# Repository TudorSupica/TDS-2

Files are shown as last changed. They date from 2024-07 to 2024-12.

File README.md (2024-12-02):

# The [TDS-2](https://github.com/TudorSupica/TDS-2/)

The TDS-2 is the next guitar pedal in the TDS series, with an improved design and use of a standard enclosure.

The main features of the TDS-2 are the use of clipping diodes and a buffering stage, before the op-amp that amplifies the base signal. I've also used a 3PDT footswitch and some audio jacks that hold the line low when no jack is inserted, just to make sure i don't get any unecessary noise.

3D_isometric

# Summary

The main features of the circuit are: 

- Buffer stage
- High amplification factor
- Clipping diodes
- Decoupling and bypass capacitors
- Standardised jack sockets, they pull the line low when not in use
- Barrel jack for power 
- 3PDT footswitch 
- Hammond 1590B Al enclosure

# [The Schematic](https://github.com/TudorSupica/TDS-2/blob/main/schematic/)

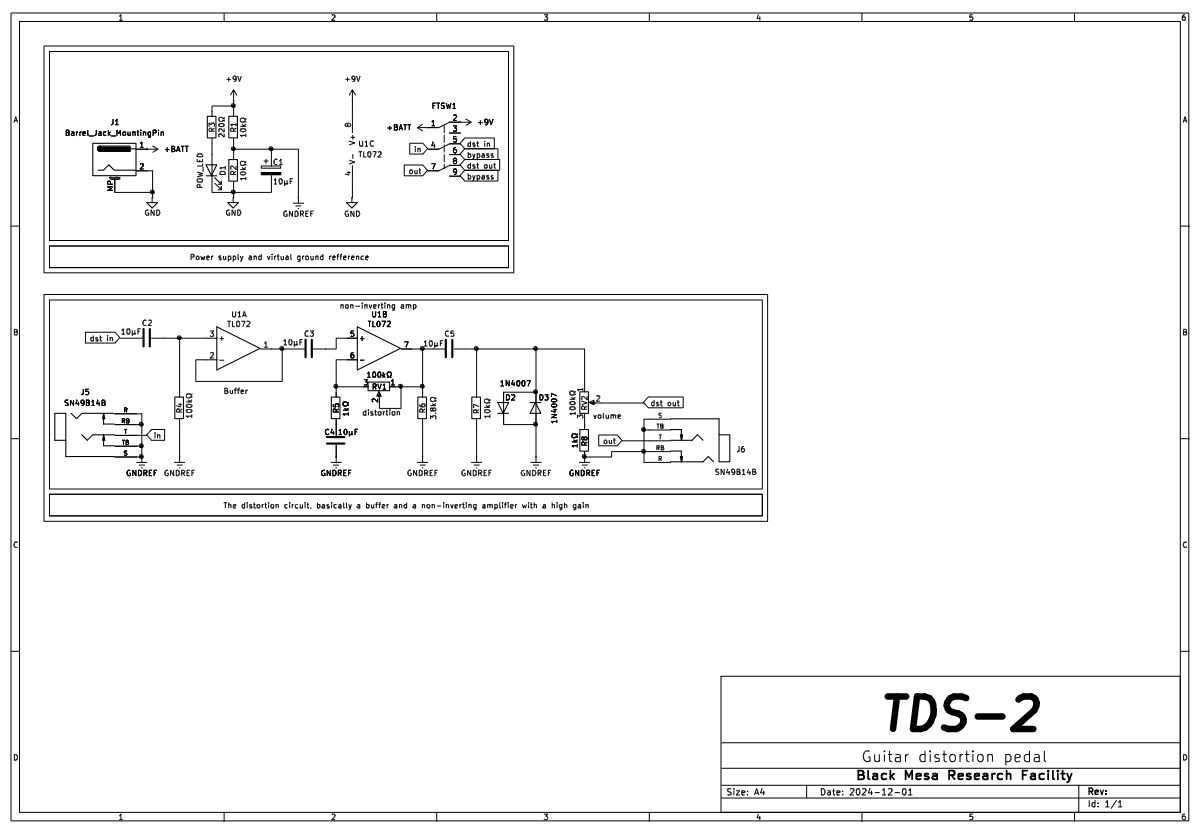
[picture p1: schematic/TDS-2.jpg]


The principle behind the TDS-2 distortion pedal is a high amplification factor. The TL072 IC has two op-amps. The first one is used as a buffer so that the imput signal is high enough. The second op-amp actually amplifies the signal, since it's in a inverting configuration to counter the phase shift of the buffer stage. 
The amplification factor is given by the potentiometer that connects the oputput back to the inverting input. The capacitors are used to decouple and "delete" any DC voltage that might be present. I used two fast switching diodes to make a clipping stage, to ensure that the signal never goes above and below the +4,5v and -4,5v headroom.

# [The PCB](https://github.com/TudorSupica/TDS-2/blob/main/PCB/)

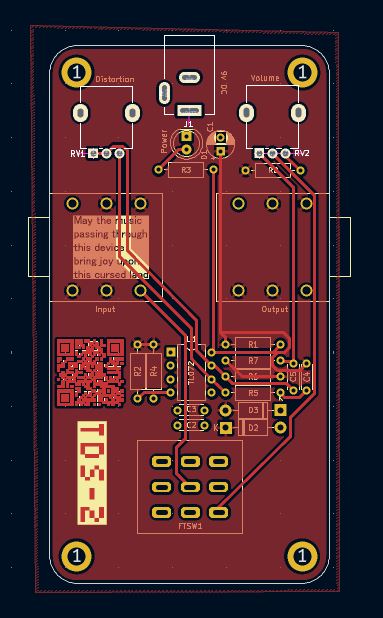
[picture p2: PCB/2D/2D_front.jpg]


The PCB also has four M3 mounting holes that are connected directly to 0v, so that when I mount it in the enclosure, the aluminium enclosure gets grounded and acts like an EMF shield.
One thing I'd improve upon are the traces since they're quite narrow and may be prone to high levels of noise.

# The Hammond 1590B enclosure

The enclosure I picked for this pedal and subsequent versions of it is the Hammond 1590B, since it's made out of aluminium it's relatively cheap and effective. The enclosure offers more of a professional look to the pedal whilst also doubling as protection against EMF and other elements.



I used this datasheet to get the dimensions needed for the PCB, and i found that 10cm x 5cm is more than enough. 

This project is not intended for beginners, but with a little guidance it can be a successful starting project.

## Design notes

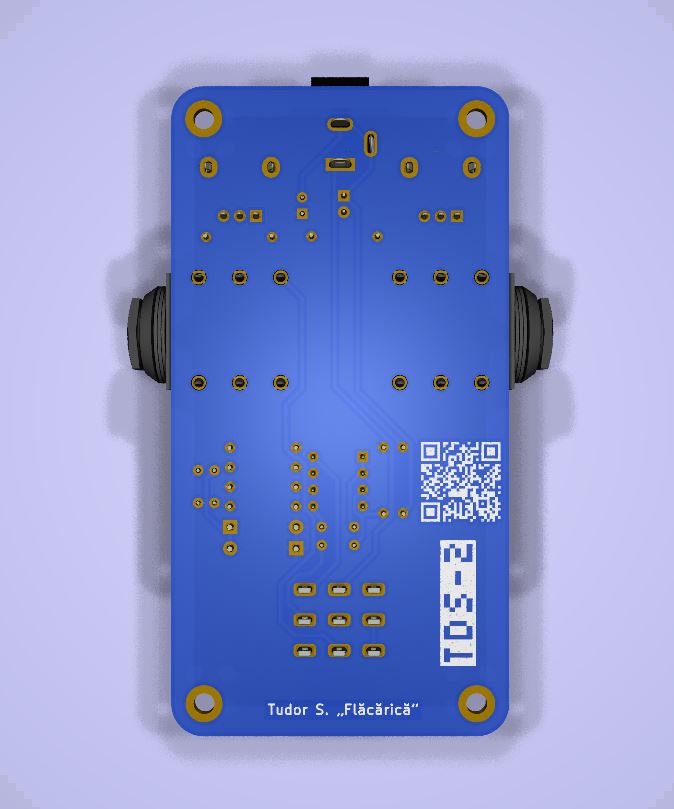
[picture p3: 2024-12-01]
PCB/3D/3D_back.jpg

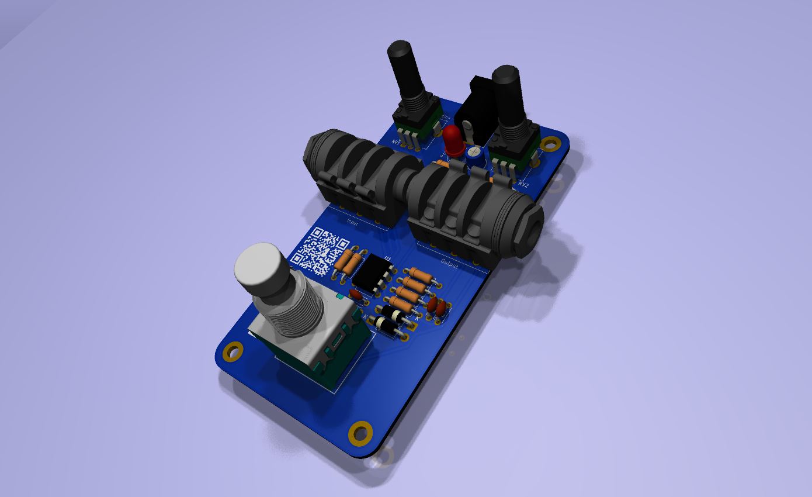
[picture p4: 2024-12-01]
PCB/3D/3D_isometric.jpg

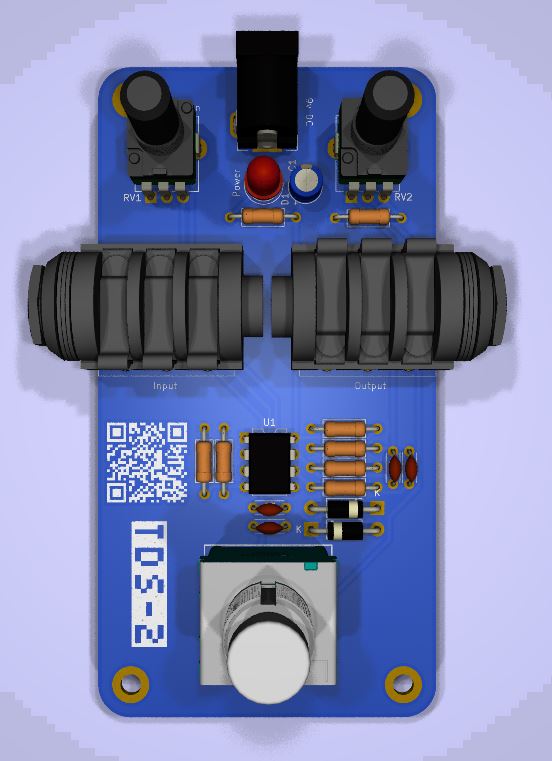
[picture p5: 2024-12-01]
PCB/3D/3D_front.jpg

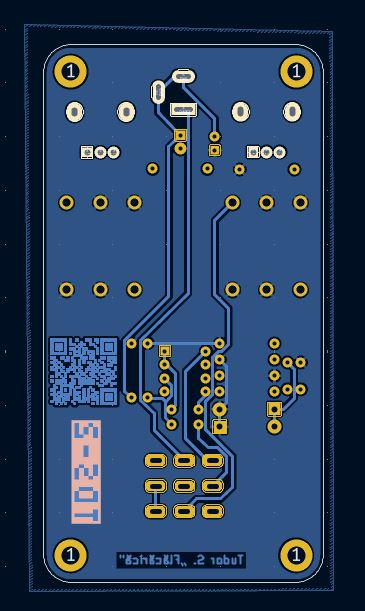
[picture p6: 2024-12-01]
PCB/2D/2D_back.jpg

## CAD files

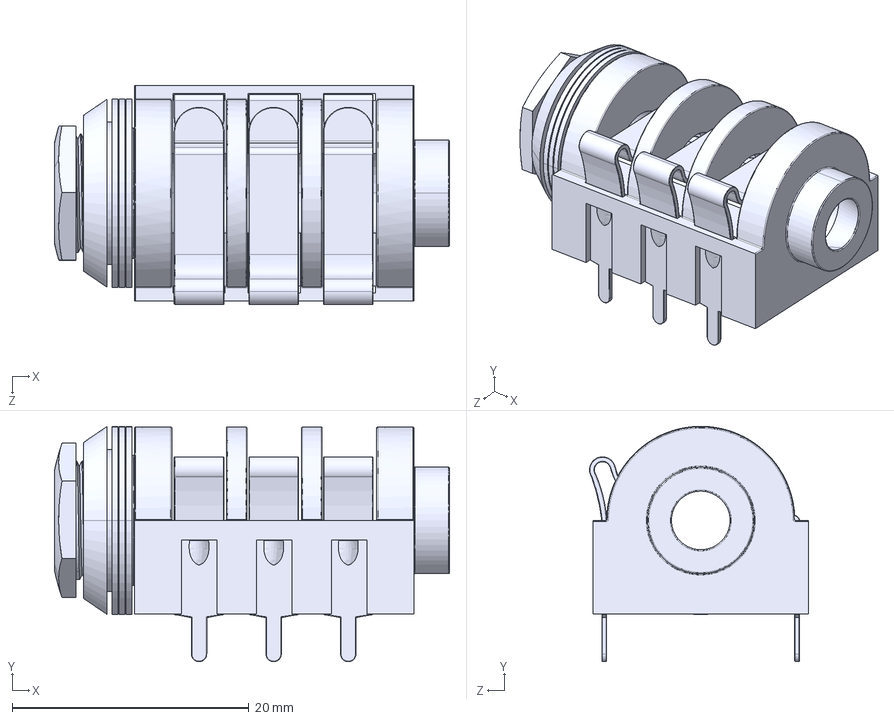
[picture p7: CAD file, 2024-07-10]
KiCAD project files/PJ644C/PC644C.IGS
33.4 x 19.9 x 18.5 mm

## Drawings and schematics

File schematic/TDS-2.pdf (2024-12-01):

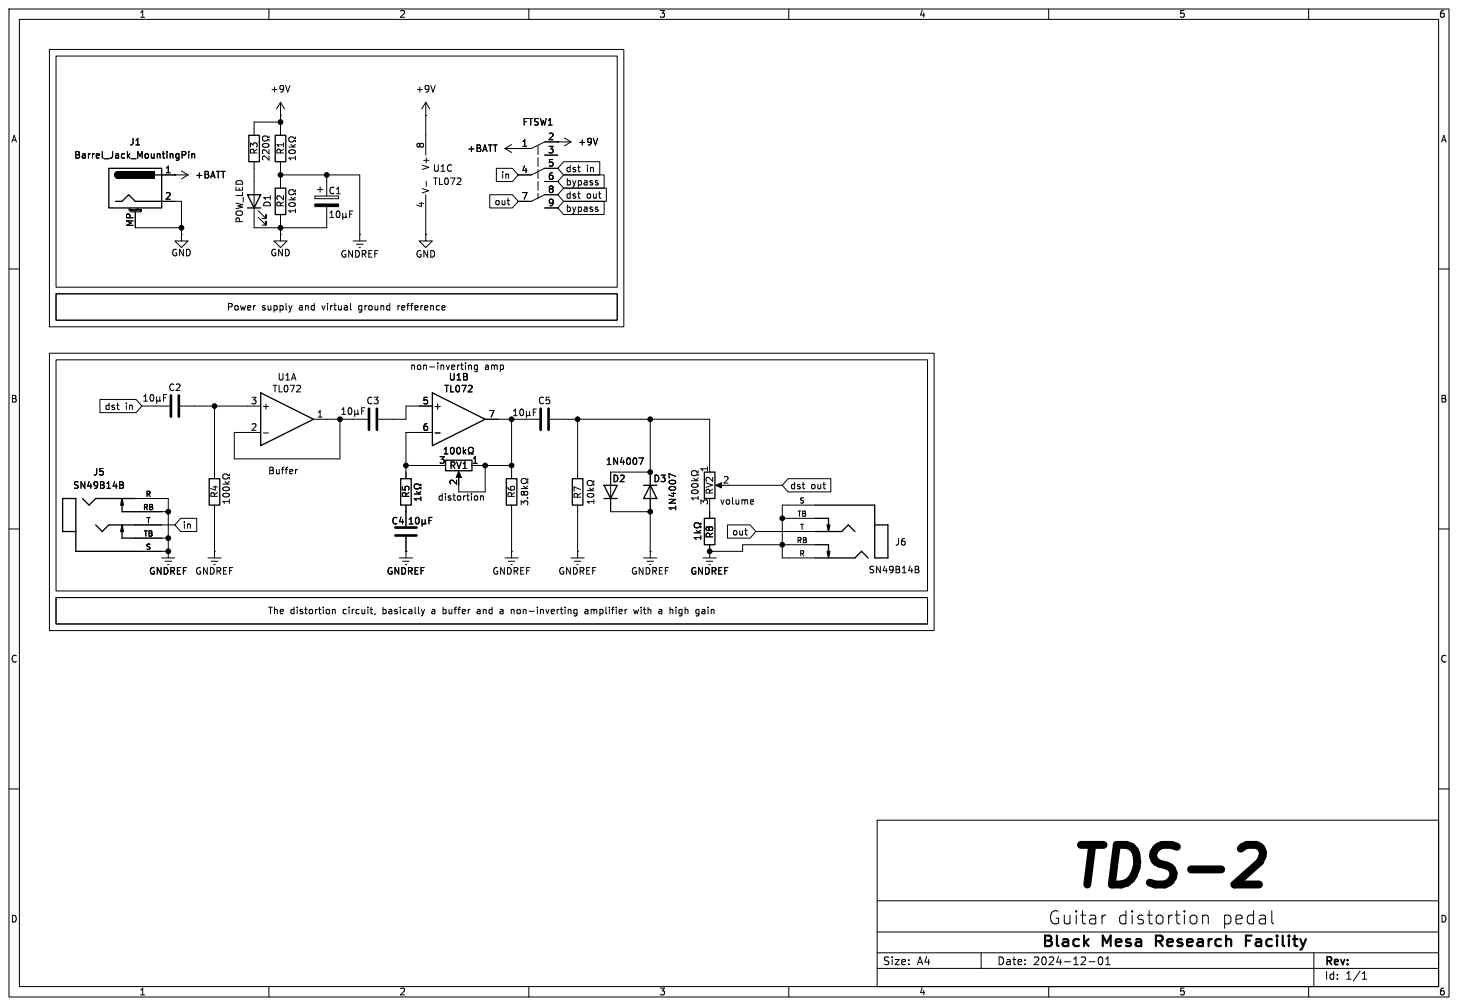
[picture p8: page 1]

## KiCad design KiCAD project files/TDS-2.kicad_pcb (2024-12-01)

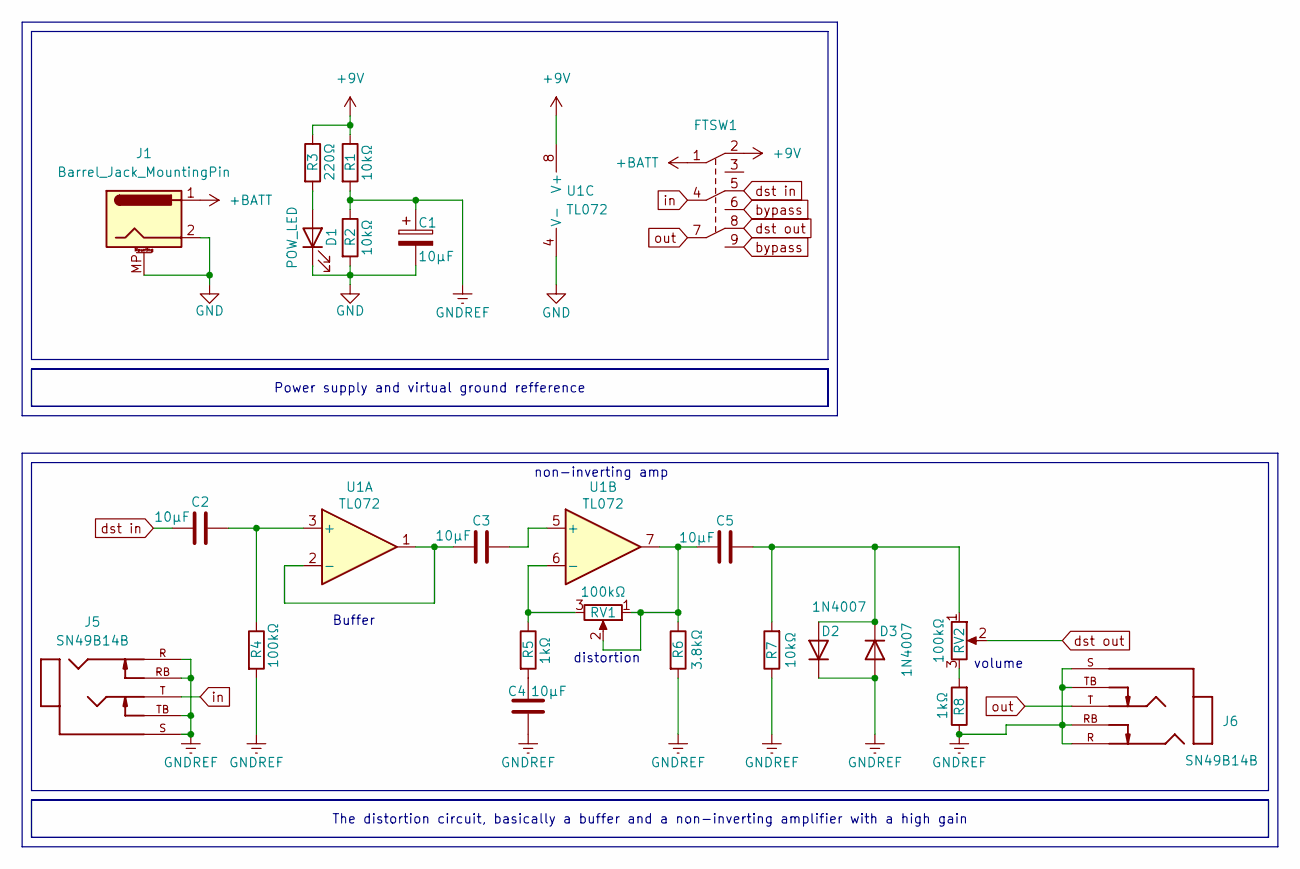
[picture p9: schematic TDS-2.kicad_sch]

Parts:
C1: 10µF; CP_Radial_D5.0mm_P2.50mm
C2, C3, C4, C5: 10µF; C_Disc_D4.3mm_W1.9mm_P5.00mm
D1: POW_LED; LED_D5.0mm
D2, D3: 1N4007; D_DO-41_SOD81_P10.16mm_Horizontal
FTSW1: 3PDT Footswitch
J1: Barrel_Jack_MountingPin; BarrelJack_Kycon_KLDX-0202-xC_Horizontal
J5, J6: SN49B14B; PJ-644C; PARTREV F
R1, R2, R7: 10kΩ; R_Axial_DIN0207_L6.3mm_D2.5mm_P10.16mm_Horizontal
R3: 220Ω; R_Axial_DIN0207_L6.3mm_D2.5mm_P10.16mm_Horizontal
R4: 100kΩ; R_Axial_DIN0207_L6.3mm_D2.5mm_P10.16mm_Horizontal
R5, R8: 1kΩ; R_Axial_DIN0207_L6.3mm_D2.5mm_P10.16mm_Horizontal
R6: 3.8kΩ; R_Axial_DIN0207_L6.3mm_D2.5mm_P10.16mm_Horizontal
RV1, RV2: 100kΩ; Potentiometer_Alpha_RD901F-40-00D_Single_Vertical
U1: TL072; DIP-8_W7.62mm

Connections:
+9V: FTSW1.2, R1.1, R3.1, U1.8 (V+)
+BATT: FTSW1.1, J1.1
GND: C1.2, D1.1 (K), J1.2, J1.MP (MountPin), R2.2, U1.4 (V-)
GNDREF: C1.1, C4.1, D2.1 (K), D3.2 (A), J5.R, J5.RB, J5.S, J5.TB, J6.R, J6.RB, J6.S, J6.TB, R1.2, R2.1, R4.2, R6.2, R7.1, R8.1
unnamed: C4.2, R5.2
unnamed: C5.1, R6.1, RV1.1, RV1.2, U1.7
unnamed: D1.2 (A), R3.2
unnamed: C5.2, D2.2 (A), D3.1 (K), R7.2, RV2.1
unnamed: R8.2, RV2.3
unnamed: C2.2, R4.1, U1.3 (+)
unnamed: C3.1, U1.1, U1.2 (-)
unnamed: C3.2, U1.5 (+)
unnamed: R5.1, RV1.3, U1.6 (-)
bypass: FTSW1.6, FTSW1.9
dst in: C2.1, FTSW1.5
dst out: FTSW1.8, RV2.2
in: FTSW1.4, J5.T
out: FTSW1.7, J6.T

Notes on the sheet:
The distortion circuit, basically a buffer and a non-inverting amplifier with a high gain
Power supply and virtual ground refference
volume
non-inverting amp
distortion
Buffer

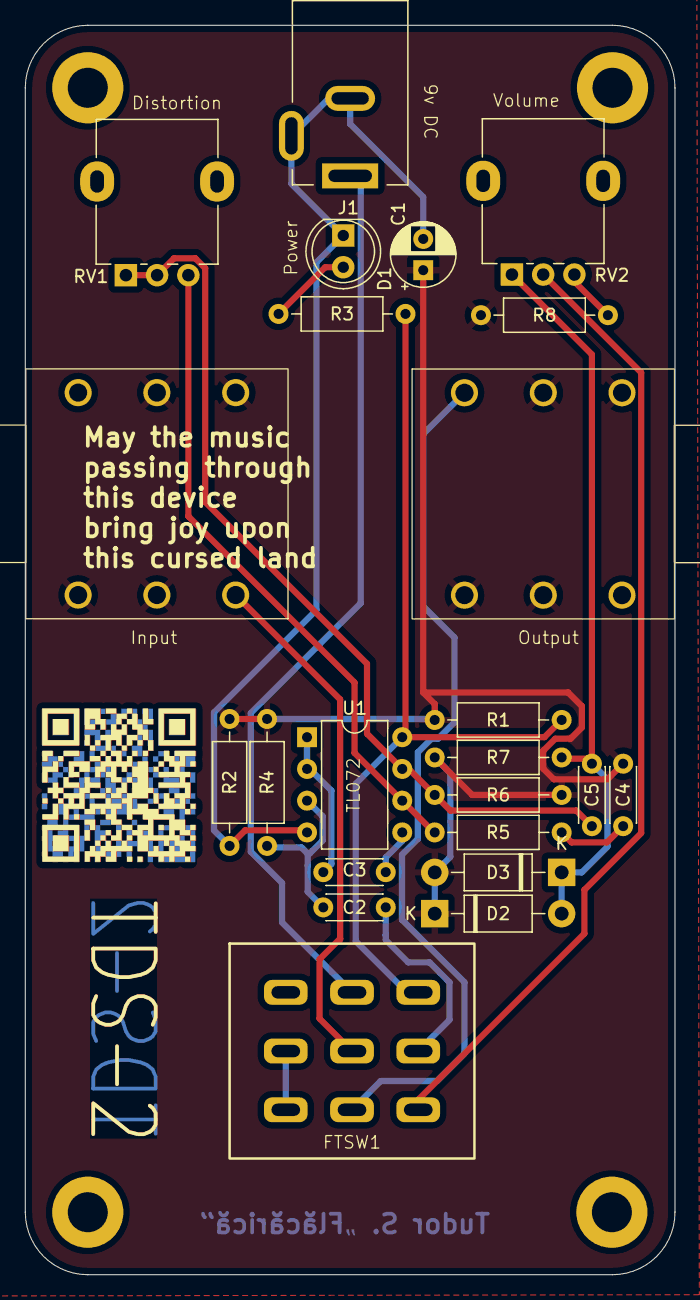
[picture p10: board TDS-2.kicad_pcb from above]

Board: 2 copper layers, 52.0 x 100.0 mm, 23 parts (0 on the bottom side), 18 nets.

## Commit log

2024-07-09 Added schematic and made the layout for the PCB
    [TDS-2.kicad_pcb, TDS-2.kicad_sch]
2024-07-10 Added schematic and PCB design
    [PC644C.IGS, TDS-2.kicad_pcb, TDS-2.kicad_sch]
2024-08-24 Changed the ground values
    [TDS-2.kicad_sch]
2024-08-24 Updated PDF schematic
2024-11-19 Update
    Updated the schematic, idk about the photos tho
    [TDS-2.kicad_pcb, TDS-2.kicad_sch]
2024-12-01 Update
    I updated the schematic PDF and the photo renders of the board
    [TDS-2-B_Cu.gbr, TDS-2-B_Mask.gbr, TDS-2-B_Paste.gbr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]
